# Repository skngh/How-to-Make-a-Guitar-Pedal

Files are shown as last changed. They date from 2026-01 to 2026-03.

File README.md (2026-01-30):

# How to Make a Digital Guitar Pedal

_by Sam Knight_

Welcome! This repository contains documentation and supporting materials for my YouTube course on how to build a digital guitar pedal using the Daisy Seed.

The goal of this course is not to clone a specific pedal, but to teach the full workflow and decision-making process behind designing, programming, and assembling your own digital guitar pedals.

## Table of Contents

- [Course Overview](#course-overview)
- [Prerequisites](#prerequisites)
- [Documentation & Resources](#documentation--resources)
  - [Bill of Materials](docs/bom.md)
  - [Resources & Links](docs/resources.md)
  - [Recommended Learning](docs/recommended-learning.md)
  - [Code](code/)
  - [Hardware](hardware/)
- [Episode Breakdown](#episode-breakdown)

## Course Overview

This course covers many topics, including:

- Setting up the **Daisy Seed** with a breadboard
- Programming a simple **hard clipping and soft clipping distortion**
- Using the **DaisySP library** to program the Daisy
- Making a **drill schematic on Tayda Electronics** for our enclosure
- Making a **full custom PCB in KiCad** with accurate part placements
- Designing a **graphic in Adobe Illustrator** to get **UV printed** onto our enclosure
- Ordering everything and **soldering** it all together

### Final Result

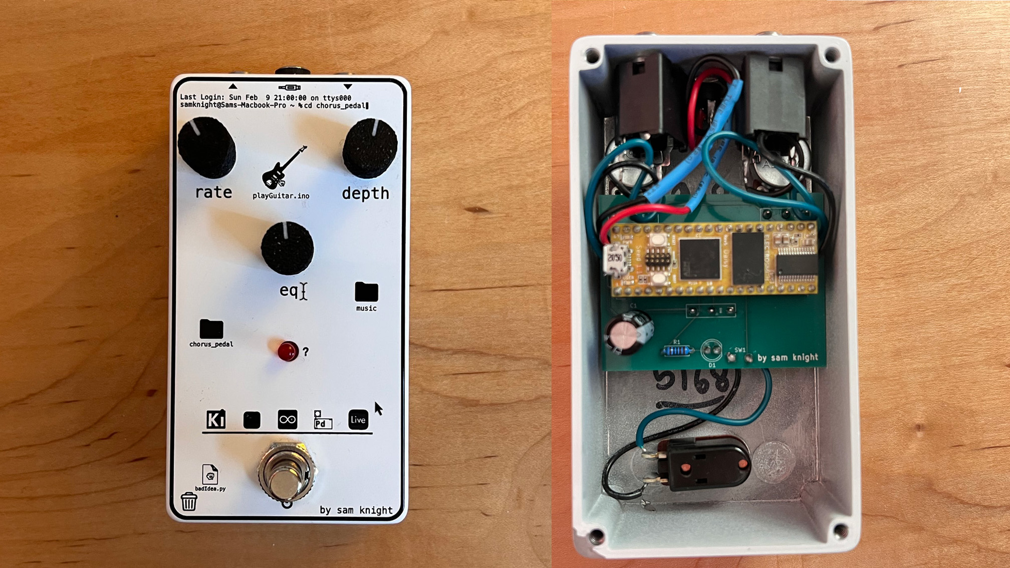
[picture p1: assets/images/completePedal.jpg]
FinishedPedal


This does not mean it is the exact pedal you will end up with. The purpose of the course is to teach the fundamentals and workflow of digital pedal design, not to produce an identical clone. You are encouraged to experiment, modify, and build something that reflects your own ideas.

## Prerequisites!

This course is intended for beginners, but not all beginners start in the same place. While the course is designed to be approachable, there are areas where having absolutely no prior experience may create friction.

That said, even if you are completely new to this space, the course can still serve as a strong foundation. If your long-term goal is to design audio-related hardware or software, this course will help identify the gaps you may want to fill going forward.

You may find parts of the course challenging if you have no experience with the following:

1. **Basic programming.** I show you how to use the DaisySP library and teach very basic DSP, but if you haven't ever written a single line of code before, there will be confusing moments. I don't go over the very basics of programming in the course, but as long as you have a simple understanding of the building blocks of any programming language, then I think you'll be fine.
2. **Very basic understanding of electrical engineering.** Going forward, if something like a "resistor" means nothing to you, then you may hit a little bottleneck with designing pedals. Don't get me wrong, to design basic circuits like we do in this course, you don't have to design anything honestly, but if you want to keep improving that will be needed moving forward. And if you have zero understanding of wiring up components and things, then there may be moments of the course that get confusing.

## Episode Breakdown

### Episode 1 — Picking Parts

Setting up the Daisy Seed on a breadboard and selecting initial components so we can begin experimenting with knobs, switches, and basic interaction.

### Episode 2 — Basic DSP

An introduction to digital signal processing and the Daisy audio callback. We use these concepts to build simple hard-clipping and soft-clipping distortion effects.

### Episode 3 — DaisySP Library

A walkthrough of the DaisySP library and how to integrate its DSP modules into your projects. We implement a basic chorus effect as a practical example.

### Episode 4 — Enclosure Drill Schematic

Creating a drill schematic using Tayda Electronics so the enclosure arrives pre-drilled and ready for assembly.

### Episode 5 — Circuit Schematic

Designing a simple circuit schematic in KiCad to connect the Daisy Seed with external components.

### Episode 6 — Footprints

Learning how to find existing footprints and create custom footprints using component datasheets.

### Episode 7 — PCB Layout & Routing

Defining the PCB outline, placing components so the board fits correctly inside the enclosure and aligns with the drill schematic, and basic PCB routing and ground plane.

### Episode 8 — Design Review & Ordering

Verifying mechanical fit, checking for common errors, and ordering the PCB through PCBWay.

### Episode 9 — UV Printing & Final Parts Order

Designing enclosure artwork for UV printing and placing final parts orders.

### Episode 10 — Final Assembly

Soldering the pedal together, testing the hardware, and applying finishing touches to the firmware.

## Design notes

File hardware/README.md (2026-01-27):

# Hardware

This folder contains all hardware-related files used throughout the course, including the PCB design, enclosure artwork, and drill schematic.

---

## PCB (KiCad)

The KiCad project files for the custom PCB designed during the course can be found in this folder.

- Open the KiCad project to view the schematic and PCB layout.
- These files correspond to [this code here.](../code/ChorusPedal/)

---

## Enclosure Graphic (Adobe Illustrator)

The enclosure artwork used for UV printing is provided as an Adobe Illustrator file.

- This file is used to generate the UV print design for Tayda.
- This is mostly for example and reference if you wanna checkout how I structured everything!

---

## Tayda Drill Schematic

Here is the Tayda drill schematic created during the course:

[Tayda Drill Schematic](https://drill.taydakits.com/box-designs/new?public_key=OXl2WFBpcTJRbzdteWcydDVlT2NJUT09Cg==)

This schematic ensures the enclosure arrives pre-drilled and aligned with the PCB layout.

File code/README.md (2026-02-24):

# Code

This folder contains all of the example code used throughout the course. Each subfolder represents a self-contained project that can be built and flashed to the Daisy Seed.

> **Important**
>
> These project folders are intended to live inside the official `DaisyExamples` directory.
>
> By default, the Makefiles assume the following structure:
>
> - `libDaisy` is located at `../../libDaisy`
> - `DaisySP` is located at `../../DaisySP`
>
> If you place these projects somewhere else, you will need to update the paths in the Makefile accordingly.

---

## Project Folders

- [ChorusPedal](./ChorusPedal)  
  The main chorus pedal project built during the course. This is final version configured for the PCB found [here](../hardware/chorus_pedal/).

- [ChorusPedalPod](./ChorusPedalPod)  
  Version of the chorus pedal that I wrote during the course, written for the Daisy Pod (not configured yet for the PCB).

- [DistortionPedalPod](./DistortionPedalPod)  
  The soft/hard clipping distortion pedal made during Pt. 2 of the course. This version is configured for the pod, where you can press a button to switch between the hard and soft clipping distortion.

- [ChorusPedalArduinoIDE](./ChorusPedalArduinoIDE)  
  A version of the chorus pedal adapted for use with the Arduino IDE instead of the standard Makefile workflow. Included for those curious.

Each folder includes its own source files and build configuration.

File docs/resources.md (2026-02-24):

# Resources

> If you're looking for the full Bill of Materials and part links, you can find that [here](bom.md).

Here are all the resources I mentioned throughout the course. This is not including any of the parts that we will be buying through Tayda Electronics or PCBWay, since I will go over buying them in each video. Those parts are linked up above.

## Equipment

### Required:

- [Daisy Seed](https://electro-smith.com/products/daisy-seed?variant=45234245108004). This is the brain of our whole pedal. You will want the 65BB version for a pedal. Getting it unsoldered can save a few bucks if you're comfortable soldering.
- Basic electronics kit, like [this one](https://www.amazon.com/EL-CK-002-Electronic-Breadboard-Capacitor-Potentiometer/dp/B01ERP6WL4?sr=8-3), OR a Daisy prototyping board like the [Daisy Pod](https://electro-smith.com/products/pod), or the [Simple Fix Kit](https://www.synthux.academy/shop/simple-fix-kit). If you go the kit route then you will have to also get some basic components, such as audio jacks, knobs, and switches. If you get a prototyping board you won't have to worry about that, but I do strongly recommend going the breadboard route if you're new. You'll get a better understanding of how microcontrollers work, and it will be cheaper overall.
- Soldering iron + soldering tools (solder, sponge cleaner, steel wool etc.). You will need a soldering iron to solder and assemble the pedal in the end. If you have never soldered before, this will be a place you will have to learn a bit of before finishing the course, as I don't teach a full beginners guide on soldering. I will say, [this](https://www.amazon.com/Soldering-Kit-Temperature-Desoldering-Electronics/dp/B07GTGGLXN?sr=8-23) was the first soldering iron I bought, and it served me well enough for about a year before I upgraded, so don't think you need to buy something expensive if it's your first iron
- 22 gauge wire (preferably stranded but solid is fine). We'll have to hand wire our jacks and footswitch to the PCB, so wire is needed.

### Optional but handy:

- Misc. tools such as wirecutters, wire strippers, helping hands.
- Multimeter. You don't need anything fancy. If you're starting off a cheap Plusivo or similar brand would be fine. I've been using this [Klein Tools MM420](https://www.amazon.com/Multimeter-Auto-Ranging-Klein-Tools-MM420/dp/B0B57PFFYX?sr=8-1) for awhile now and haven't had any issues. If you plan on getting into electronics, this device is an absolute must for debugging and understanding your circuits.

## Links

- [Daisy Seed Documentation](https://daisy.audio/)
- [DaisySP Library Documentation](https://github.com/electro-smith/DaisySP)
- [Tayda Electronics](https://www.taydaelectronics.com/)
- [PCBWay](https://www.pcbway.com/)
- [3D Printed Knob Caps (Spline Shaft)](https://makerworld.com/en/models/1096300-spline-shaft-potentiometer-knob-cap#profileId-1090701)

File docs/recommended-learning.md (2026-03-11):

# Learning resources

If you are feeling overwhelmed starting off, here are a few resources for each category that I found helpful when I began my journey. I think it would still be helpful to go through the course first, but these can be great afterwards

**Coding:**

- [Harvard's CS50](https://harvardonline.harvard.edu/course/cs50-introduction-computer-science). This was my intro to programming course I did to get started. This would obviously be for those very serious about wanting to learn programming, but I promise if you get through it you will have a very strong foundation going forward. It is more than enough to get started building digital pedals!
- [Learn C++](https://www.learncpp.com/). This is a great online resource for learning C++. If you don't care for the more broad learning that something like CS50 will give you, resources like this are a great place to learn more targeted languages.
- [The Cherno C++ Series](https://www.youtube.com/watch?v=18c3MTX0PK0&list=PLlrATfBNZ98dudnM48yfGUldqGD0S4FFb). Great youtube series that really gives in depth knowledge on how each little thing in C++ works. Great for if you're transitioning from another language that's higher level and you want a better explanation of how each thing works in the language.
- Just code! If you're just starting off, simple tutorials on the basic will suffice and then I recommend just jumping into fun projects (like pedals!). Since coding using something like the DaisySP library is fairly simple, it can really help building that foundation before writing your own DSP classes.

**DSP:**

- [The Scientist and Engineer's Guide to Digital Signal Processing](https://www.dspguide.com/pdfbook.htm). This is a fantastic online resource that covers sooo many amazing DSP topics. If you can get through this you will be very well set going forward.
- [Will Pirkle books](https://www.willpirkle.com/). I haven't read these myself but hear great things about them. They're more plugin focused but all the DSP will still apply to the Daisy!
- [The Audio Programmer](https://www.youtube.com/@TheAudioProgrammer). Great channel full of amazing lectures and courses all related to audio programming (obviously!). Most of the tutorials are about building plugins, which I highly recommend if you are trying to build pedals! Plugins can be just as fun, and most all the techniques apply to both.
- Learn math! If you want to unlock the true world of DSP, math is your best friend. You don't have to be an expert, or even that intermediate (I'm sure not), but I personally found I kept hitting walls because of my lack in math. I didn't have to take any math classes in college so I pretty much lost all my math knowledge. I found that [Khan Academy](https://www.khanacademy.org/) is still a great resource, especially if you're regurarly applying math while programming. It may not be the best single resource, but as long as you're doing other steps to apply your teachings, it should work well. But my favorite math youtube channel is [3Blue1Brown](https://www.youtube.com/c/3blue1brown).

**Buffers and Impedance! (as talked about in episode 10)**

- Amazing site where you can see [famous pedal's schematics.](https://www.electrosmash.com/)
  <br><br>Op amp buffer resources:
- https://www.allaboutcircuits.com/video-tutorials/op-amp-applications-voltage-follower/
- https://effectpedalkits.com/effect-pedal-circuits-the-buffer/
- https://www.youtube.com/watch?v=PvGdRVg5QXY&list=PLfYdTiQCV_p6tWY5Wwjgefa7AX2YiDRQ4&index=3
  <br><br>
  Learn about impedance!
- https://www.youtube.com/watch?v=TjC1Zbm4xpc&t=46s
- https://www.youtube.com/watch?v=3QtpaICzSNc&t=50s

**Electrical Engineering**

- There's many great channels out there that will just teach you the basics of different components and formulas. [The Engineering Mindset](https://www.youtube.com/@EngineeringMindset/videos) and [ElectroBOOM](https://www.youtube.com/@ElectroBOOM/videos) are two of the biggest ones.
- This is another massive field so the resources you want will depend on how deep you want to go. Starting off just getting familiar with different basic components and Ohms law will get you far. Eventually, I felt I needed a firmer background so I'm currently going through [this](https://www.udemy.com/course/crash-course-electronics-and-pcb-design/) Udemy course taught by Andre LaMothe, and really recommend it. It's definitely slow, coming in at around 100+ hours, but it's teaching me tons. [This book](https://www.amazon.com/Practical-Electronics-Inventors-Fourth-Scherz/dp/1259587541) by Paul Scherz and Simon Monk has also been helpful, but it's definitely a bit dense if you're new
- If you're really just interested in microcontroller world, than simply finding fun arduino projects is always a good time and learning experience. A lot of that knowledge can apply to the Daisy Seed too! You could also venture into modular synth building world with the Daisy, which I can't recommend enough.

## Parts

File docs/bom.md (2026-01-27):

# Bill of Materials (BOM)

> Prices are approximate and reflect a snapshot as of **January 2026** (excluding tax).

This is the BOM for the exact chorus pedal I make throughout the course. It won't fluctuate that much in price honestly (except for shipping), so this is a good reference point no matter how many knobs/switches you add. Since we order the enclosure/UV/drilling through Tayda, I'm going to list all parts from Tayda too.

_**The price factors in the quantity.**_

| Part | Vendor Link | Quantity | Price |
| --- | --- | ---: | ---: |
| Daisy Seed | [Electro-Smith](https://electro-smith.com/products/daisy-seed?variant=45234245140772) | 1 | $24 (unsoldered) |
| 125B Style Aluminum Diecast Enclosure White | [Tayda](https://www.taydaelectronics.com/98788-dup-125b-style-aluminum-diecast-enclosure.html) | 1 | $6 |
| 125B ENCLOSURE CUSTOM DRILL SERVICE | [Tayda](https://www.taydaelectronics.com/125b-custom-drill-enclosure-service.html) | 1 | $4.50 |
| 125B ENCLOSURE FACE UV PRINTING SERVICE | [Tayda](https://www.taydaelectronics.com/125b-uv-printing-service.html) | 1 | $4 |
| ADDITIONAL SERVICE FOR GLOSS LAYER ENCLOSURE CUSTOM UV PRINTING SERVICE | [Tayda](https://www.taydaelectronics.com/custom-uv-gloss-layer-service.html) | 1 | $2 |
| 10K OHM Linear Taper Potentiometer PC Mount | [Tayda](https://www.taydaelectronics.com/b-10k-ohm-linear-taper-potentiometer-with-pc-mount.html) | 3 | $1.80 |
| 6.35mm 1/4" MONO Phone Jack | [Tayda](https://www.taydaelectronics.com/6-35mm-1-4-mono-phone-jack-6040.html) | 2 | $0.90 |
| SPST Momentary Soft Touch Short Shaft Push Button Stomp Foots / Pedal Switch | [Tayda](https://www.taydaelectronics.com/spst-momentary-soft-touch-short-shaft-push-button-stomp-foots-pedal-switch.html) | 1 | $1.97 |
| DC Power Jack 2.1mm Panel Mount Round | [Tayda](https://www.taydaelectronics.com/dc-power-jack-2-1mm-round-type-panel-mount-1.html) | 1 | $0.28 |
| 20 Pin 2.54mm Single Row Female Pin Header | [Tayda](https://www.taydaelectronics.com/20-pin-2-54-mm-single-row-female-pin-header.html) | 2 | $0.56 |
| LED 5mm Red | [Tayda](https://www.taydaelectronics.com/led-5mm-red.html) | 1 | $0.024 |
| 1K Resistor | [Tayda](https://www.taydaelectronics.com/10-x-resistor-1k-ohm-1-4w-1-metal-film-pkg-of-10.html) | 1 | $0.015 |
| PCB | [PCBWay](https://www.pcbway.com/) | 5 boards (minimum order) | ~$1 each (~$5 total) |
| Tayda shipping | — | (assumed ordered all at once) | ~$15 |
| Daisy Seed shipping | — | 1 | ~$5 |
| PCBWay shipping | — | 1 | ~$5 |
| **Estimated total (1 pedal)** | — | — | **~$76** |

## BUY BULK MATERIALS!

If you're hoping to make more pedals after this, buy parts in bulk. Not only does the individual price drop when buying higher quantities, but shipping costs are also better dispersed. Once you have your PCB design finalized, you can order that layout in bulk and then do separate UV print designs for each pedal.

This can easily bring the per-pedal cost down to around $50, and even lower if you're making multiple units of the same design.

Either way, there's no reason not to buy many resistors, LEDs, pots, jacks etc. They are so cheap so you're simply saving money in the long run.

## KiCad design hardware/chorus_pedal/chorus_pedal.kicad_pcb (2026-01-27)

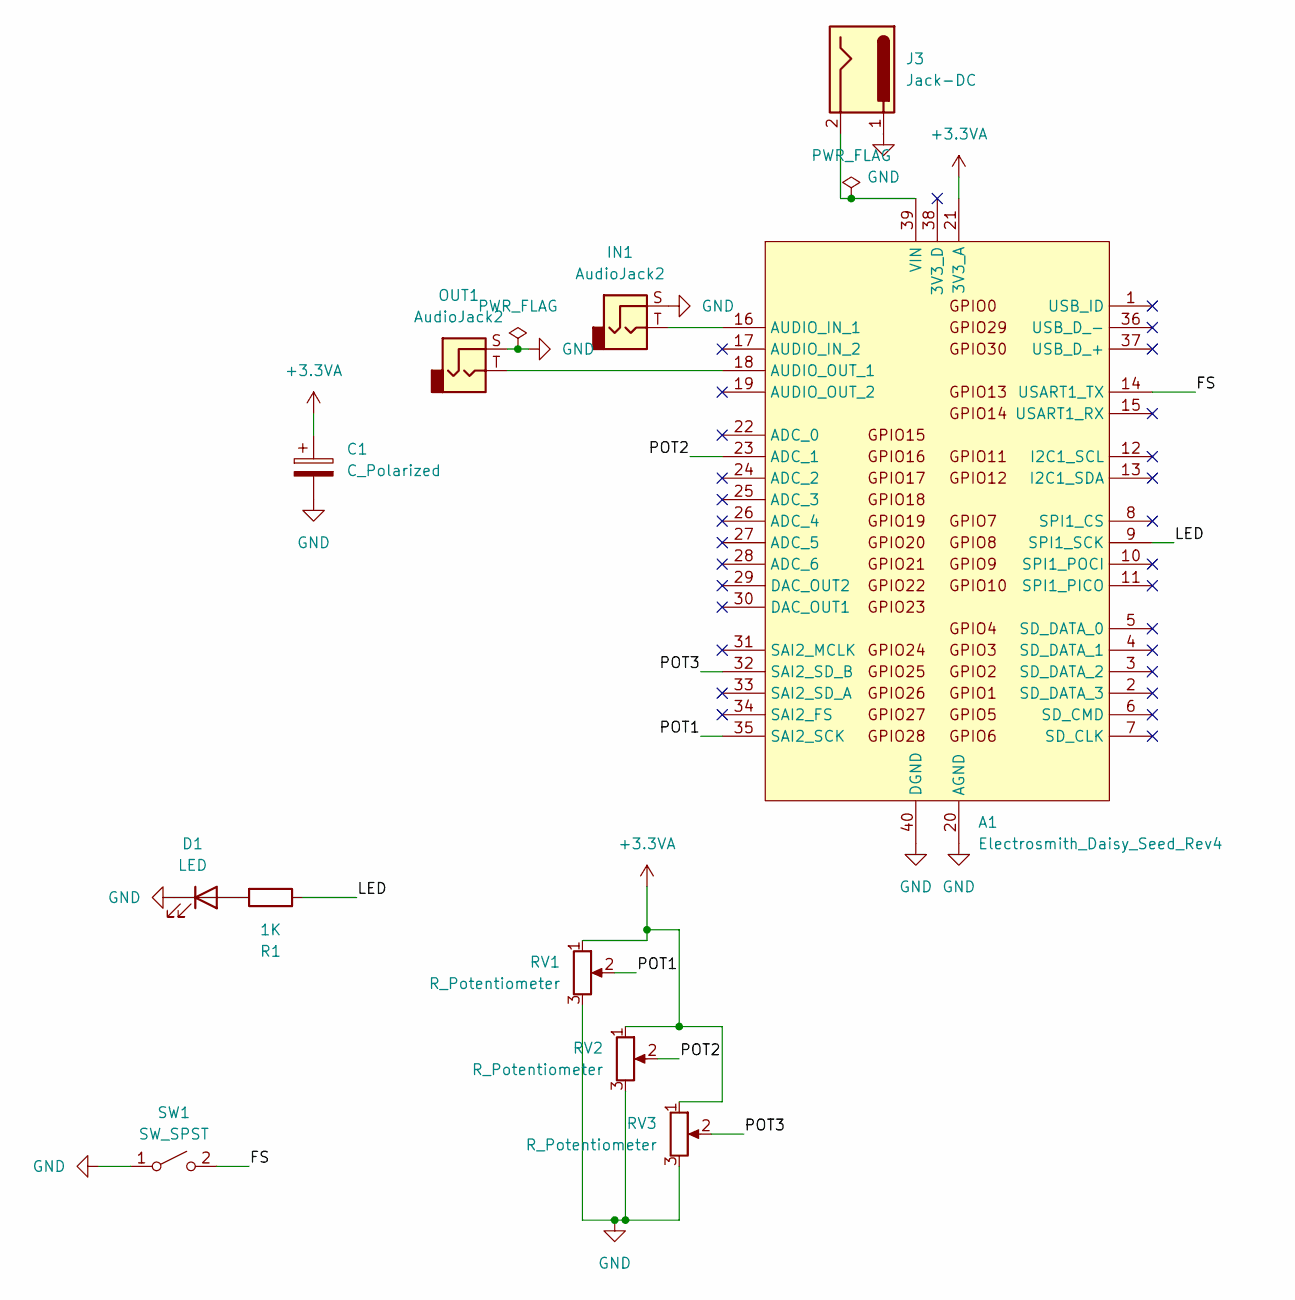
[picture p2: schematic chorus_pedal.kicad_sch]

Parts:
A1: Electrosmith_Daisy_Seed_Rev4; Electrosmith_Daisy_Seed
C1: C_Polarized; CP_Radial_D10.0mm_P2.50mm
D1: LED; LED_D5.0mm
IN1: AudioJack2; SolderWire-0.5sqmm_1x02_P4.6mm_D0.9mm_OD2.1mm
J3: Jack-DC; SolderWire-0.5sqmm_1x02_P4.6mm_D0.9mm_OD2.1mm
OUT1: AudioJack2; SolderWire-0.5sqmm_1x02_P4.6mm_D0.9mm_OD2.1mm
R1: 1K; R_Axial_DIN0207_L6.3mm_D2.5mm_P7.62mm_Horizontal
RV1, RV2, RV3: R_Potentiometer; RV16AF-41
SW1: SW_SPST; SolderWire-0.5sqmm_1x02_P4.6mm_D0.9mm_OD2.1mm

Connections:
+3.3VA: A1.21 (3V3_A), C1.1, RV1.1, RV2.1, RV3.1
/FS: A1.14 (USART1_TX), SW1.2 (B)
/LED: A1.9 (SPI1_SCK), R1.1
/POT1: A1.35 (SAI2_SCK), RV1.2
/POT2: A1.23 (ADC_1), RV2.2
/POT3: A1.32 (SAI2_SD_B), RV3.2
GND: A1.20 (AGND), A1.40 (DGND), C1.2, D1.1 (K), IN1.S, J3.1, OUT1.S, RV1.3, RV2.3, RV3.3, SW1.1 (A)
unnamed: A1.16 (AUDIO_IN_1), IN1.T
unnamed: A1.18 (AUDIO_OUT_1), OUT1.T
unnamed: A1.39 (VIN), J3.2
unnamed: D1.2 (A), R1.2

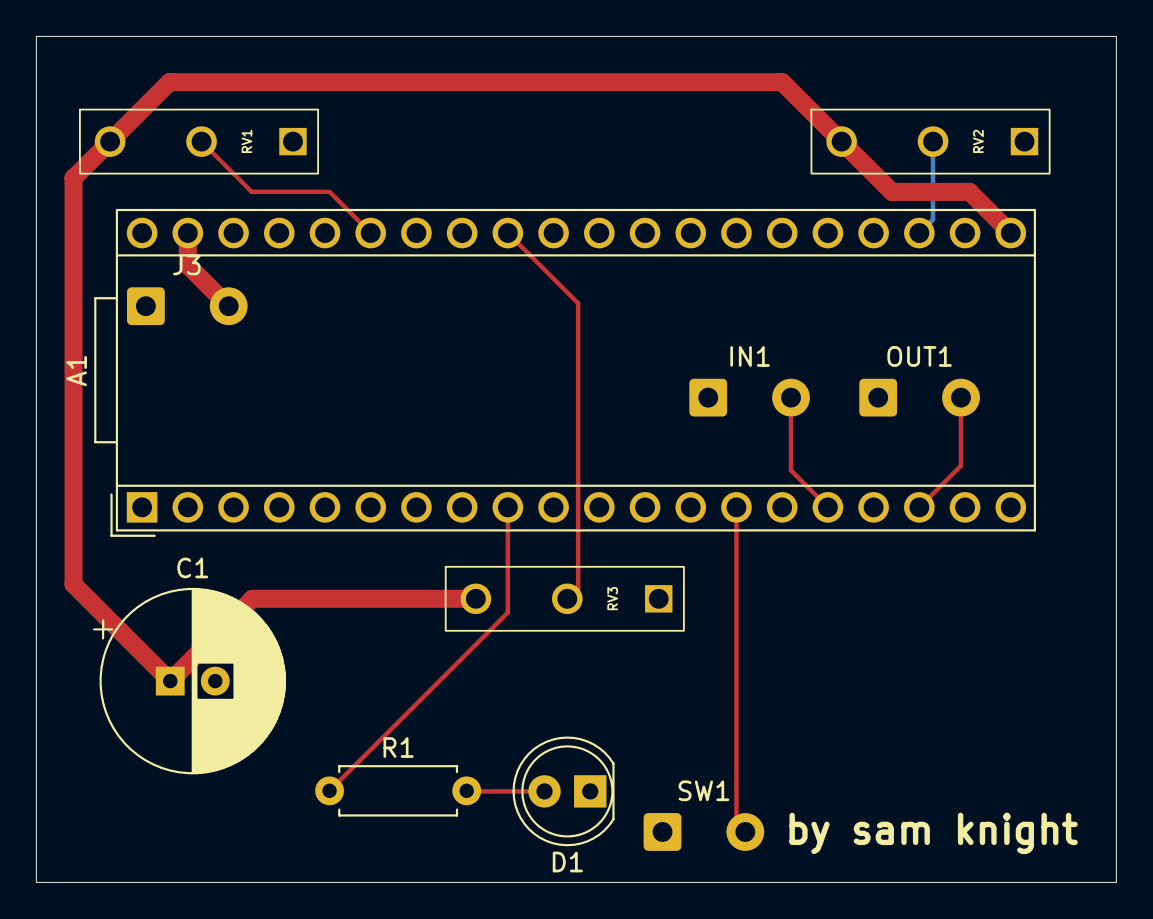
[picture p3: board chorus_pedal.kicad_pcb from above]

Board: 2 copper layers, 60.0 x 47.0 mm, 11 parts (0 on the bottom side), 11 nets.

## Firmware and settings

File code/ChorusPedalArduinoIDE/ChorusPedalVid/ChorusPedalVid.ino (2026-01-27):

#include "DaisyDuino.h"

DaisyHardware hw;

size_t num_channels;

#define LED D8
#define POT1 A1
#define POT2 A11
#define POT3 A10
#define FOOTSWITCH D13

bool bypass = true;

static MoogLadder lpf;
static Chorus chorus;
float feedback = 0.3;
float delayMs = 15;
float rate, depth, cutoff;

Switch footswitch;

void MyCallback(float **in, float **out, size_t size) {
  float wet;

  ProcessADC();

  for (size_t i = 0; i < size; i++) {
    wet = lpf.Process(chorus.Process(in[0][i]));


    out[0][i] = bypass ? in[0][i] : ((wet * 0.75) + (in[0][i] * 0.25));
  }
}

void setup() {
  float samplerate;
  // Initialize for Daisy pod at 48kHz
  hw = DAISY.init(DAISY_SEED, AUDIO_SR_48K);
  num_channels = hw.num_channels;
  samplerate = DAISY.get_samplerate();

  chorus.Init(samplerate);
  chorus.SetDelayMs(delayMs);
  chorus.SetFeedback(feedback);
  lpf.Init(samplerate);
  lpf.SetRes(0);


  pinMode(LED_BUILTIN, OUTPUT);
  pinMode(LED, OUTPUT);

  digitalWrite(LED_BUILTIN, HIGH);

  footswitch.Init(1000, true, FOOTSWITCH, INPUT_PULLUP);

  DAISY.begin(MyCallback);
}

void loop() {}
void ProcessADC()
{
  footswitch.Debounce();
  bypass ^= footswitch.RisingEdge();
  digitalWrite(LED, !bypass);

  rate = fmap(analogRead(POT1) / 1023.0, .1, 5, daisysp::Mapping::EXP);
  depth = fmap(analogRead(POT2) / 1023.0, 0, 1, daisysp::Mapping::EXP);
  cutoff = fmap(analogRead(POT3) / 1023.0, 500, 5000, daisysp::Mapping::LOG);

  chorus.SetLfoFreq(rate);
  chorus.SetLfoDepth(depth);
  lpf.SetFreq(cutoff);
}

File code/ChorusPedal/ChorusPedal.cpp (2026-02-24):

#include "daisy_seed.h"
#include "daisysp.h"

using namespace daisy;
using namespace daisy::seed;
using namespace daisysp;

DaisySeed hw;

enum AdcChannel
{
    knobOne,
    knobTwo,
    knobThree,
    NUM_ADC_CHANNELS
};

void InitializeADC();
void ProcessADC();

#define LED D8
#define POT1 A1
#define POT2 A11
#define POT3 A10
#define FOOTSWITCH D13

bool bypass = true;

OnePole lpf;
Chorus chorus;
float feedback = 0.3;
float delayMs = 15;
float rate, depth, cutoff;
GPIO led;

Switch footswitch;

void AudioCallback(AudioHandle::InputBuffer in,
                   AudioHandle::OutputBuffer out,
                   size_t size)
{
    float wet;

    ProcessADC();

    for (size_t i = 0; i < size; i++)
    {
        wet = lpf.Process(chorus.Process(in[0][i]));

        if (bypass)
            out[0][i] = in[0][i];
        else
            out[0][i] = (wet * 0.75) + (in[0][i] * 0.25);
    }
}

int main(void)
{
    hw.Init();
    hw.SetAudioBlockSize(4); // number of samples handled per callback
    hw.SetAudioSampleRate(SaiHandle::Config::SampleRate::SAI_48KHZ);

    float sampleRate = hw.AudioSampleRate();

    InitializeADC();

    chorus.Init(sampleRate);
    chorus.SetFeedback(feedback);
    chorus.SetDelayMs(delayMs);

    lpf.Init();
    lpf.SetFilterMode(OnePole::FilterMode::FILTER_MODE_LOW_PASS);
    lpf.SetFrequency(cutoff);

    hw.StartAudio(AudioCallback);

    while (1)
    {
    }
}

void InitializeADC()
{
    AdcChannelConfig adc_config[NUM_ADC_CHANNELS];
    adc_config[knobOne].InitSingle(POT1);
    adc_config[knobTwo].InitSingle(POT2);
    adc_config[knobThree].InitSingle(POT3);

    led.Init(LED, GPIO::Mode::OUTPUT, GPIO::Pull::NOPULL);
    footswitch.Init(FOOTSWITCH);
    hw.SetLed(!bypass);

    hw.adc.Init(adc_config, NUM_ADC_CHANNELS);
    hw.adc.Start();
}

void ProcessADC()
{
    footswitch.Debounce();
    bypass ^= footswitch.RisingEdge();
    led.Write(!bypass);

    rate = fmap(hw.adc.GetFloat(knobOne), .1, 5, daisysp::Mapping::EXP);
    depth = fmap(hw.adc.GetFloat(knobTwo), 0, 1, daisysp::Mapping::EXP);
    cutoff = fmap(hw.adc.GetFloat(knobThree), 500, 15000, daisysp::Mapping::LOG);

    chorus.SetLfoFreq(rate);
    chorus.SetLfoDepth(depth);
    lpf.SetFrequency(cutoff);
}

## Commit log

2026-01-27 added everything
    [chorus_pedal.kicad_pcb, chorus_pedal.kicad_sch]
2026-01-30 added more sketches
    [chorus_pedal.kicad_sch]
